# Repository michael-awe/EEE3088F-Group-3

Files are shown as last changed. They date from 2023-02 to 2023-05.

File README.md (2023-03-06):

# EEE3088F Project (Group 3)

This GitHub repository contains the source code and documentation for a sound and proximity light sensing HAT (Hardware Attached on Top) designed for an STM32F05C6T6 Discovery board. The repository contains detailed technical documentation with diagrams, schematics and specifications for the HAT's hardware and software.

## Project Description
Our HAT (Hardware Attached on Top) is a compact device that incorporates light proximity sensor and a sound sensor, making it an all-in-one solution for non-contact detection and monitoring. Designed to work seamlessly with STM 32 microcontrollers, the HAT offers both motion and sound sensing capabilities that make it an ideal choice for a wide range of use cases such as process monitoring, home automation, surveillance, and non-contact activation.  
With an onboard battery, the HAT can operate remotely for extended periods, providing reliable and accurate data capture during load-shedding. The HAT's data capture capabilities are enhanced by its micro-USB data transfer, which allows users to easily power the microcontroller and transfer data between it and a computer. Overall, the HAT is an excellent option for businesses and organizations looking for a cost-effective, reliable, and adaptable solution for non-contact detection and monitoring. 

## Team Members
1. Michael Awe (Microcontroller interfacing + Coding)
2. Adrian Mc Intosh (Sensor Module)
3. Simon Carthew (Power Module)

## License

This repository is licensed under the Creative Commons Attribution 4.0 International license. See `LICENSE.md` for more information.

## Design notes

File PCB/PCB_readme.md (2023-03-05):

# PCB

A folder to store all the KiCAD libraries aswell as the gerber and schematic files for the HAT.

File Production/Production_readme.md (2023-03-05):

# Production

A folder to store all the information a manufacturer may need to produce the HAT, as well as information concerning the budget surrounding the board.

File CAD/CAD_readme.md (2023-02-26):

# CAD_readme
Folder containg files related to mechanical design for the project such as 3D printing or container design files

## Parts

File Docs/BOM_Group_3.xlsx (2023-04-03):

JLCPCB PART NUM | MANUFACTURER PART NO. | EXTENDED PART | JLCPCB PART LINK | KICAD SCHEMATIC REFERENCE | COMPONENT VALUE | QTY PER BOARD | QTY FIVE BOARDS | PRICE PER UNIT ($) | PRICE PER BOARD ($) | PRIVE FIVE BOARDS ($) | PRICE FIVE BOARDS EXTENDED ($)
C15008 | CC0805KRX7R9BB104 | 0 | https://jlcpcb.com/partdetail/15681-CL31A107MQHNNNE/C15008 | C6 | 100u | 1 | 5 | 0.0046 | 0.0046 | 0.023 | 0.023 | SENSOR MODULE TOTALS
C28323 | CL21B105KBFNNNE | 0 | https://jlcpcb.com/partdetail/29074-CL21B105KBFNNNE/C28323 | C7 | 4.7u | 1 | 15 | 0.0095 | 0.0095 | 0.1425 | 0.1425 | One Board | $3.60
C149504 | 0805W8F1003T5E | 0 | https://jlcpcb.com/partdetail/160838-0805W8F1003T5E/C149504 | R23,R24 | 100k | 2 | 10 | 0.0017 | 0.0034 | 0.017 | 0.017 | Five Boards | $18.02
C4310 | 0805W8F1501T5E | 0 | https://jlcpcb.com/partdetail/4717-0805W8F1501T5E/C4310 | R 19 | 1.5k | 1 | 5 | 0.0018 | 0.0018 | 0.009 | 0.009
C17379 | 0805W8F1201T5E | 0 | https://jlcpcb.com/partdetail/18067-0805W8F1201T5E/C17379 | R 20 | 1.2k | 1 | 5 | 0.0018 | 0.0018 | 0.009 | 0.009 | MICROCONTROLLER MODULE TOTALS
C2655167 | VL6180V1NR/1 | 1 | https://test.jlcpcb.com/partdetail/Stmicroelectronics-VL6180V1NR1/C2655167 | VL6180 | PROX SENSOR | 1 | 5 | 2.0786 | 2.0786 | 10.393 | 13.393 | One Board | $3.54
C75510 | LM317AG-TN3-R | 0 | https://jlcpcb.com/partdetail/utc_unisonic_tech-LM317AG_TN3R/C75510 | Q8 | LM317AG | 1 | 5 | 0.1872 | 0.1872 | 0.936 | 0.936 | Five Boards | $17.72
C78284 | BSS138 | 1 | https://jlcpcb.com/partdetail/79418-BSS138/C78284 | Q4, Q6, Q7, Q8 | BSS138 | 4 | 15 | 0.0225 | 0.09 | 0.3375 | 3.3375
C17414 | 0805W8F1002T5E | 0 | 0805W8F1002T5E | UNI-ROYAL(Uniroyal Elec) | Chip Resistor - Surface Mount | JLCPCB (https://jlcpcb.com/partdetail/18102-0805W8F1002T5E/C17414) | R38, R39, R40, R41, R46, R47, R48, R49 | 10k | 8 | 15 | 0.00133333 | 0.01066664 | 0.01999995 | 0.01999995
C17477 | 0805W8F0000T5E | 0 | https://jlcpcb.com/partdetail/18165-0805W8F0000T5E/C17477 | R18,R21,R22,R25,R37,R43,R44,R50,R36,R42,R45,R51 | 0k | 12 | 60 | 0.0022 | 0.0264 | 0.132 | 0.132 | POWER MODULE TOTALS
 |  |  |  |  |  |  |  |  |  |  |  | One Board | $1.29
 |  |  |  |  |  |  |  |  |  |  |  | Five Boards | $9.46
JLCPCB PART NUM | MANUFACTURER PART NO. | EXTENDED PART | JLCPCB PART LINK | KICAD SCHEMATIC REFERENCE | COMPONENT VALUE | QTY PER BOARD | QTY FIVE BOARDS | PRICE PER UNIT ($) | PRICE PER BOARD ($) | PRIVE FIVE BOARDS ($) | PRICE FIVE BOARDS EXTENDED ($)
C7171 | TAJA106K016RNJ | 0 | https://jlcpcb.com/partdetail/KyoceraAvx-TAJA106K016RNJ/C7171 | C1, C4 | 10uF | 2 | 10 | 0.088 | 0.176 | 0.88 | 0.88
C49678 | CC0805KRX7R9BB104 | 0 | https://jlcpcb.com/partdetail/Yageo-CC0805KRX7R9BB104/C49678 | C8 | 0.1u | 1 | 5 | 0.0046 | 0.0046 | 0.023 | 0.023 | HAT TOTALS
C2286 | KT-0603R | 0 | https://jlcpcb.com/partdetail/Hubei_KentoElec-KT0603R/C2286 | LED1 | Red LED | 1 | 5 | 0.006 | 0.006 | 0.03 | 0.03 | Sensor Module | $18.02
C2297 | C2297 | 0 | https://jlcpcb.com/partdetail/Hubei_KentoElec-C2297/C2297 | LED2 | Green LED | 1 | 5 | 0.0133 | 0.0133 | 0.0665 | 0.0665 | Power Module | $9.46
C17414 | 0805W8F1002T5E | 0 | https://jlcpcb.com/partdetail/18102-0805W8F1002T5E/C17414 | R5, R6 | 10k | 2 | 10 | 0.00133333 | 0.00266666 | 0.0133333 | 0.0133333 | MicroController Interfacing | $17.72
C17477 | 0805W8F0000T5E | 0 | https://jlcpcb.com/partdetail/18165-0805W8F0000T5E/C17477 | R1, R2, R7, R8, R9, R17 | 0k | 6 | 30 | 0.0022 | 0.0132 | 0.066 | 0.066 | Manufacturing | $12.00
C17927 | C17927 | 0 | https://jlcpcb.com/partdetail/18615-1206W4F1004T5E/C17927 | R11, R13 | 1M | 2 | 10 | 0.0031 | 0.0062 | 0.031 | 0.031 | GRAND TOTAL | $57.20
C17927 | GZ2012D101TF | 0 | https://jlcpcb.com/partdetail/Sunlord-GZ2012D101TF/C1015 | R15, R16 | 100 | 2 | 10 | 0.0094 | 0.0188 | 0.094 | 0.094
C2857251 | ZMM2V0 | 1 | https://jlcpcb.com/partdetail/Jsmsemi-ZMM2V0/C2857251 | D2, D3 | D_Zener | 1 | 5 | 0.0103 | 0.0103 | 0.0515 | 3.0515
C4172 | 0603WAF1504T5E | 0 | https://jlcpcb.com/partdetail/4579-0603WAF1504T5E/C4172 | R10, R11 | 1.5M | 2 | 10 | 0.0017 | 0.0034 | 0.017 | 0.017
C22764 | 0603WAF1101T5E | 0 | https://jlcpcb.com/partdetail/23491-0603WAF1101T5E/C22764 | R3, R4, R14 | 1k | 3 | 15 | 0.002 | 0.006 | 0.03 | 0.03
C191023 | 1N5819WS | 0 | https://jlcpcb.com/partdetail/GuangdongHottech-1N5819WS/C191023 | D1, D2 | 1N5819 | 2 | 10 | 0.162 | 0.324 | 1.62 | 1.62
C7433 | OP07CDR | 0 | https://jlcpcb.com/partdetail/TexasInstruments-OP07CDR/C7433 | U3 | OP07 | 1 | 5 | 0.28 | 0.28 | 1.4 | 1.4
C8492 | LBSS84LT1G | 0 | https://jlcpcb.com/partdetail/Lrc-LBSS84LT1G/C8492 | Q2, Q3 | LBSS84LT1G | 2 | 10 | 0.0242 | 0.0484 | 0.242 | 0.242
C5446 | XC6206P332MR | 0 | https://jlcpcb.com/partdetail/TorexSemicon-XC6206P332MR/C5446 | U2 | XC6206P | 1 | 5 | 0.0964 | 0.0964 | 0.482 | 0.482
C15127 | AO3401A | 0 | https://jlcpcb.com/partdetail/Alpha_OmegaSemicon-AO3401A/C15127 | Q1 | AO3401A | 1 | 5 | 0.0797 | 0.0797 | 0.3985 | 0.3985
C16581 | TP4056-42-ESOP8 | 0 | https://jlcpcb.com/partdetail/17264-TP4056_42ESOP8/C16581 | U1 | TP4056 | 1 | 5 | 0.2027 | 0.2027 | 1.0135 | 1.0135
JLCPCB PART NUM | MANUFACTURER PART NO. | EXTENDED PART | JLCPCB PART LINK | KICAD SCHEMATIC REFERENCE | COMPONENT VALUE | QTY PER BOARD | QTY FIVE BOARDS | PRICE PER UNIT ($) | PRICE PER BOARD ($) | PRICE FIVE BOARDS ($) | PRICE FIVE BOARDS EXTENDED ($)
C404969 | MICROXNJ | 1 | https://jlcpcb.com/partdetail/ShouHan-MicroXNJ/C404969 | J6 | Micro-B USB Connector | 1 | 5 | 0.03 | 0.03 | 0.15 | 3.15
C79987 | CAT24C256WI-GT3 | 1 | https://jlcpcb.com/partdetail/Onsemi-CAT24C256WIGT3/C79987 | U6 | EEPROM | 1 | 5 | 0.43 | 0.43 | 2.15 | 5.15
C84681 | CH340C | 1 | https://jlcpcb.com/partdetail/wch_jiangsu_Qin_heng-CH340C/C84681 | U7 | USB to Serial | 1 | 5 | 0.47 | 0.47 | 2.35 | 5.35
C17477 | 0805W8F0000T5E | 0 | https://jlcpcb.com/partdetail/18165-0805W8F0000T5E/C17477 | R26, R27, R28, R31, R32, R33, R34, R35 | 0k | 8 | 40 | 0.0022 | 0.0176 | 0.088 | 0.088
C49678 | CC0805KRX7R9BB104 | 0 | https://jlcpcb.com/partdetail/Yageo-CC0805KRX7R9BB104/C49678 | C12 | 0.1uF | 1 | 5 | 0.0046 | 0.0046 | 0.023 | 0.023
C23162 | 0603WAF4701T5E | 0 | https://jlcpcb.com/parts/2nd/Resistors/Chip_Resistor_Surface_Mount_4 | R29, R30 | 4.7K | 2 | 10 | 0.001 | 0.002 | 0.01 | 0.01
C1525 | CL05B104KO5NNNC | 0 | https://jlcpcb.com/partdetail/1877-CL05B104KO5NNNC/C1525 | C13, C14 | 100nF | 2 | 10 | 0.01 | 0.02 | 0.1 | 0.1
C19666 | CL10A475KO8NNNC | 0 | https://jlcpcb.com/partdetail/20375-CL10A475KO8NNNC/C19666 | C15 | 4.7uF | 1 | 5 | 0.01 | 0.01 | 0.05 | 0.05
C15195 | CL05B103KB5NNNC | 0 | https://jlcpcb.com/partdetail/15869-CL05B103KB5NNNC/C15195 | C16 | 10nF | 1 | 5 | 0.01 | 0.01 | 0.05 | 0.05
C52923 | CL05A105KA5NQNC | 0 | https://jlcpcb.com/partdetail/53938-CL05A105KA5NQNC/C52923 | C17 | 1uF | 1 | 5 | 0.01 | 0.01 | 0.05 | 0.05
C107114 | CC0805JRNPO9BN300 | 0 | https://jlcpcb.com/partdetail/Yageo-CC0805JRNPO9BN300/C107114 | C10,C11 | 30pF | 2 | 10 | 0.01 | 0.02 | 0.1 | 0.1
C252310 | 6CS08000F20UCG | 1 | https://jlcpcb.com/partdetail/247485-6CS08000F20UCG/C252310 | Y1 | 8MHz, 20pF | 1 | 5 | 0.12 | 0.12 | 0.6 | 3.6

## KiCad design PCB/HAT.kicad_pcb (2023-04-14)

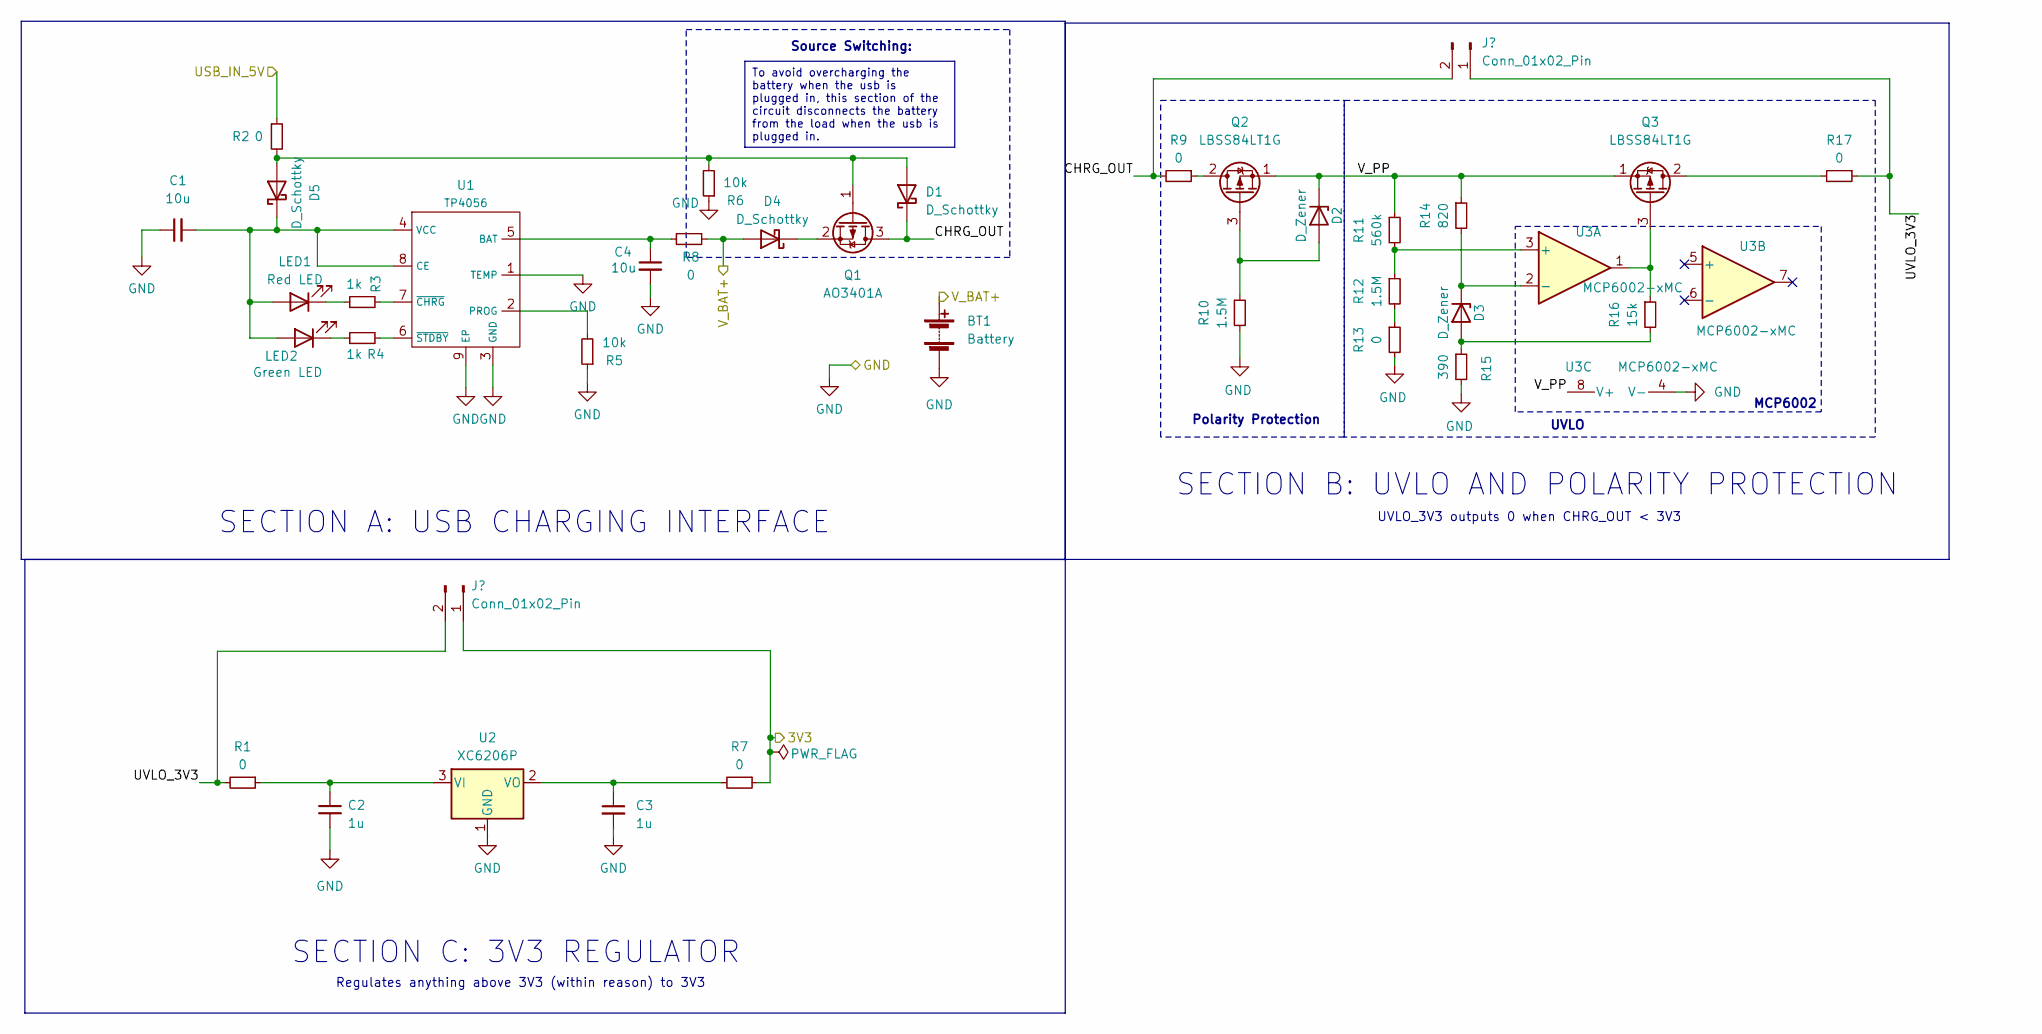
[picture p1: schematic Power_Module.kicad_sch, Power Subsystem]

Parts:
BT1: Battery; 18650_Holder_SMD
C1, C4: 10u; CAP-SMD_L3.2-W1.6-RD-C7171
C2, C3: 1u; C0402_NEW
D1, D4, D5: D_Schottky; SOD-323_L1.8-W1.3-LS2.5-RD
D2, D3: D_Zener; LL-34_L3.5-W1.5-RD
J1, J2: Conn_01x02_Pin; PinHeader_1x02_P2.54mm_Vertical
LED1: Red LED; LED0603-RD
LED2: Green LED; LED0805-R-RD
Q1: AO3401A; SOT-23
Q2, Q3: LBSS84LT1G; SOT-23_L2.9-W1.3-P1.90-LS2.4-BR
R1, R2, R7, R8, R9, R13, R17: 0; R_0805_2012Metric
R3, R4: 1k; R_0805_2012Metric
R5, R6: 10k; R_0805_2012Metric
R10: 1.5M; R_0805_2012Metric
R11: 560k; R_0603_1608Metric
R12: 1.5M; R_0603_1608Metric
R14: 820; R_0805_2012Metric
R15: 390; R_0805_2012Metric
R16: 15k; R_0805_2012Metric
U1: TP4056; SOIC-8-1EP_3.9x4.9mm_P1.27mm_EP2.29x3mm
U2: XC6206P; SOT-23-3
U3: MCP6002-xMC; DFN-8-1EP_3x2mm_P0.5mm_EP1.75x1.45mm

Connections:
/MicroController_Interfacing/3V3: J1.1, R7.1; also elsewhere on the board
/MicroController_Interfacing/USB 5V: R2.1; also elsewhere on the board
/Power Module/CHRG_OUT: D1.1 (K), J2.2, Q1.3 (D), R9.2
/Power Module/UVLO_3V3: J1.2, J2.1, R1.2, R17.1
/Power Module/V_BAT+: BT1.1 (+), D4.2 (A), R8.1; also elsewhere on the board
/Power Module/V_PP: D2.1 (K), Q2.1 (S), Q3.1 (S), R11.1, R14.1, U3.8 (V+)
GND: BT1.2 (-), C1.1, C2.2, C3.2, C4.2, R5.1, R6.1, R10.2, R13.2, R15.2, U1.1 (TEMP), U1.3 (GND), U1.9 (EP), U2.1 (GND), U3.4 (V-), U3.9 (V-); also elsewhere on the board
unnamed: D1.2 (A), D5.2 (A), Q1.1 (G), R2.2, R6.2
unnamed: D2.2 (A), Q2.3 (G), R10.1
unnamed: D3.2 (A), R15.1, R16.2
unnamed: D3.1 (K), R14.2, U3.2 (-)
unnamed: D4.1 (K), Q1.2 (S)
unnamed: C1.2, D5.1 (K), LED1.2 (A), LED2.2 (A), U1.4 (VCC), U1.8 (CE)
unnamed: LED1.1 (K), R3.1
unnamed: LED2.1 (K), R4.1
unnamed: Q2.2 (D), R9.1
unnamed: Q3.2 (D), R17.2
unnamed: Q3.3 (G), R16.1, U3.1
unnamed: R12.2, R13.1
unnamed: C4.1, R8.2, U1.5 (BAT)
unnamed: R5.2, U1.2 (PROG)
unnamed: R3.2, U1.7 (~CHRG)
unnamed: R4.2, U1.6 (~STDBY)
unnamed: C2.1, R1.1, U2.3 (VI)
unnamed: C3.1, R7.2, U2.2 (VO)
unnamed: R11.2, R12.1, U3.3 (+)

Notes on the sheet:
To avoid overcharging the battery when the usb is plugged in, this section of the circuit disconnects the battery from the load when the usb is plugged in.
Source Switching:
MCP6002
SECTION C: 3V3 REGULATOR
UVLO
SECTION B: UVLO AND POLARITY PROTECTION
SECTION A: USB CHARGING INTERFACE
UVLO_3V3 outputs 0 when CHRG_OUT < 3V3
Regulates anything above 3V3 (within reason) to 3V3
Polarity Protection

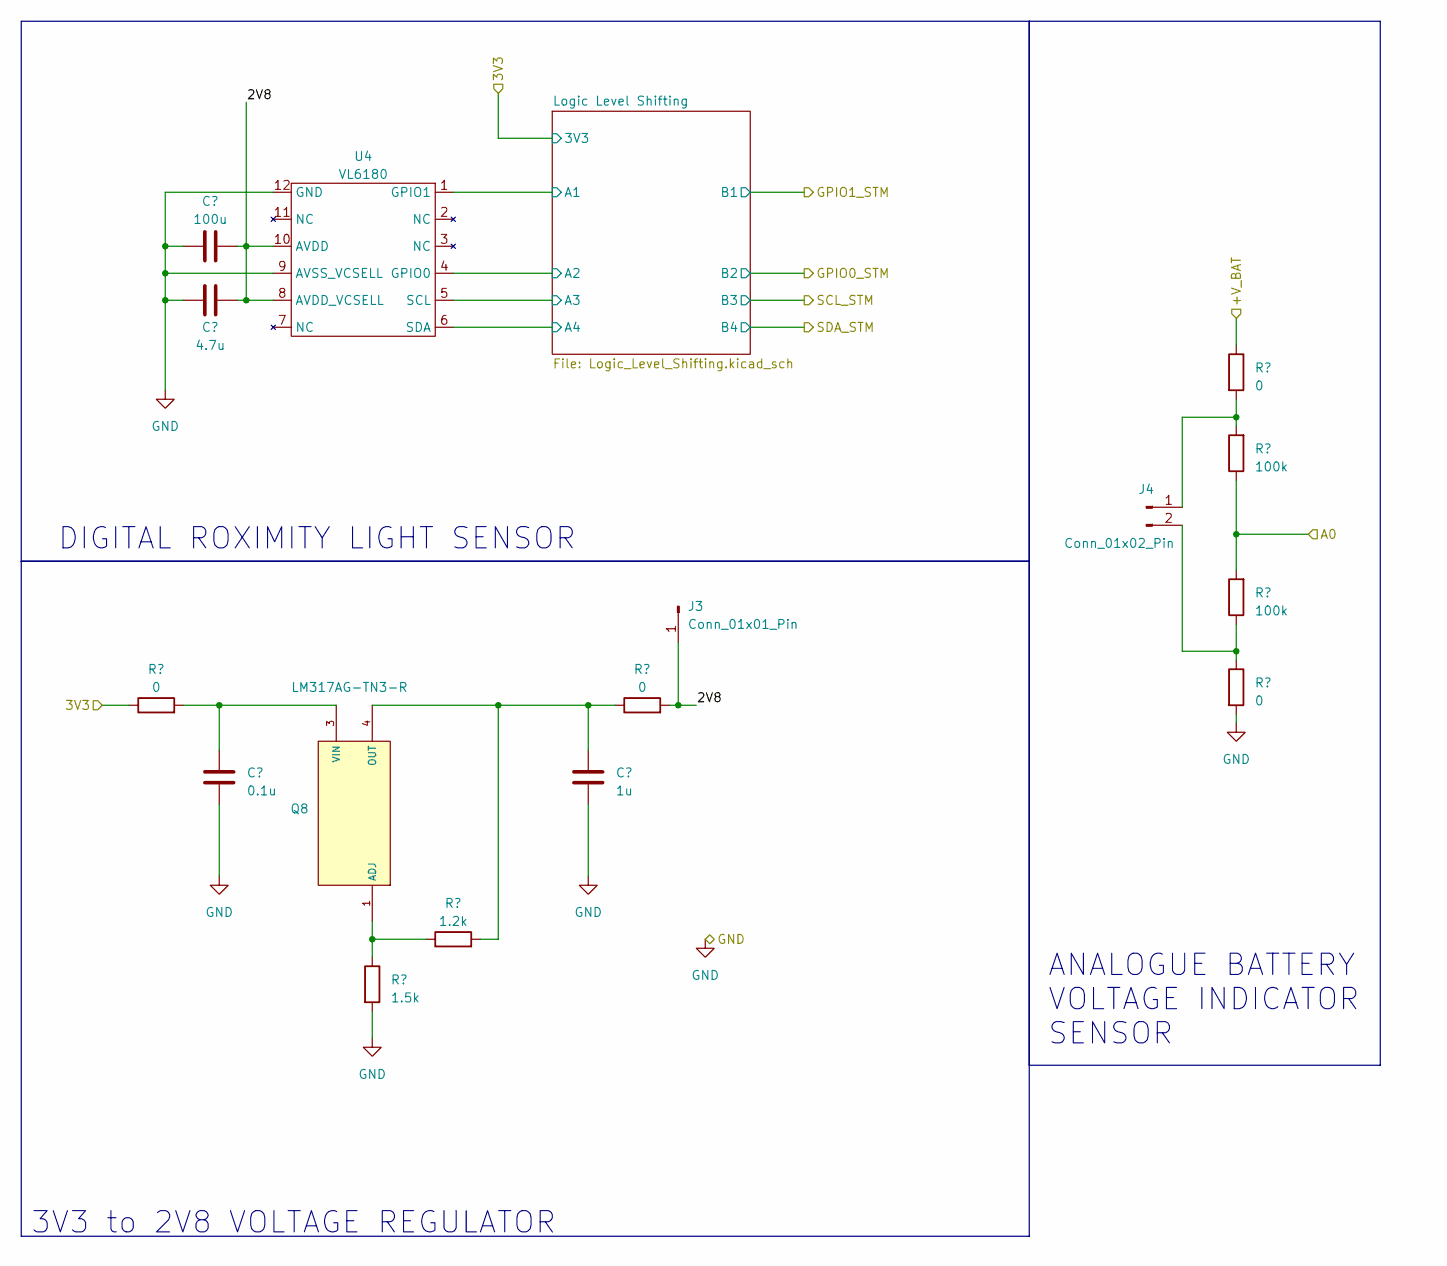
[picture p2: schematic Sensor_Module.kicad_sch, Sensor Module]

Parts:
C6: 100u; C1206
C7: 4.7u; C0603
C8: 0.1u; C0805
C9: 1u; C0402_NEW
J3: Conn_01x01_Pin; PinHeader_1x01_P2.54mm_Vertical
J4: Conn_01x02_Pin; PinHeader_1x02_P2.54mm_Vertical
Q8: LM317AG-TN3-R; TO-252-2_L6.5-W6.1-P4.58-LS10.0-TL; LCSC C75510
R18, R21, R22, R25: 0; R_0805_2012Metric
R19: 1.5k; R_0805_2012Metric
R20: 1.2k; R_0805_2012Metric
R23, R24: 100k; R_0805_2012Metric
U4: VL6180; LGA-12_L4.8-W2.8-P0.75-BL

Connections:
/MicroController_Interfacing/3V3: R18.1; also elsewhere on the board
/MicroController_Interfacing/A0: R23.1, R24.2; also elsewhere on the board
/Power Module/V_BAT+: R22.1; also elsewhere on the board
/Sensor Module/2V8: C6.1, C7.1, J3.1, R21.2, U4.8 (AVDD_VCSELL), U4.10 (AVDD)
/Sensor Module/Logic Level Shifting/A1: U4.1 (GPIO1); also elsewhere on the board
/Sensor Module/Logic Level Shifting/A2: U4.4 (GPIO0); also elsewhere on the board
/Sensor Module/Logic Level Shifting/A3: U4.5 (SCL); also elsewhere on the board
/Sensor Module/Logic Level Shifting/A4: U4.6 (SDA); also elsewhere on the board
GND: C6.2, C7.2, C8.1, C9.1, R19.2, R25.2, U4.9 (AVSS_VCSELL), U4.12 (GND); also elsewhere on the board
unnamed: J4.1, R22.2, R23.2
unnamed: J4.2, R24.1, R25.1
unnamed: Q8.1 (ADJ), R19.1, R20.1
unnamed: C9.2, Q8.4 (OUT), R20.2, R21.1
unnamed: C8.2, Q8.3 (VIN), R18.2

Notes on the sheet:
ANALOGUE BATTERY VOLTAGE INDICATOR SENSOR
DIGITAL ROXIMITY LIGHT SENSOR
3V3 to 2V8 VOLTAGE REGULATOR

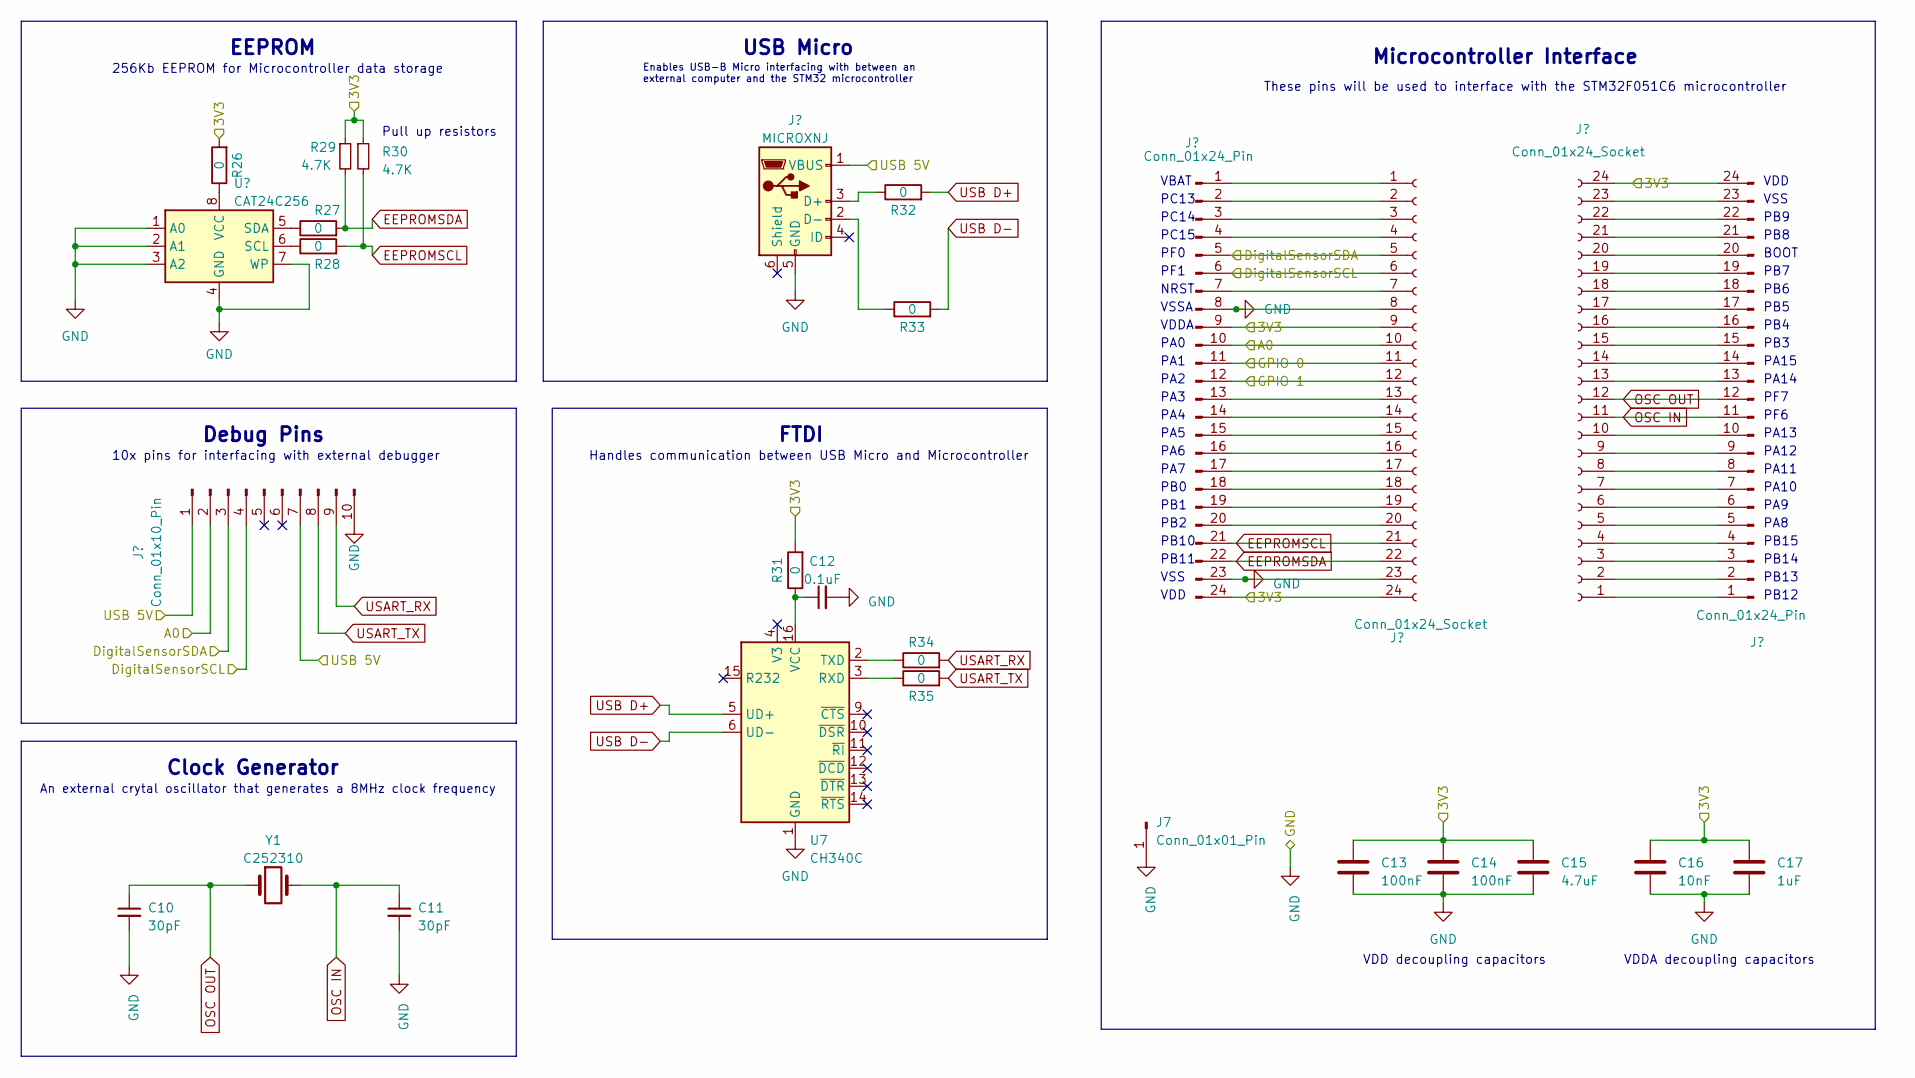
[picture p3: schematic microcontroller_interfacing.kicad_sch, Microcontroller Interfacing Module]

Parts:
C10, C11: 30pF; C0805
C12: 0.1uF; C0805
C13, C14: 100nF; C0402
C15: 4.7uF; C0603
C16: 10nF; C0402_NEW
C17: 1uF; C0402_NEW
J5: Conn_01x10_Pin; PinHeader_1x10_P2.54mm_Vertical
J6: MICROXNJ; USB_Conn_JLC_LCSC_C404969
J7: Conn_01x01_Pin; PinHeader_1x01_P2.54mm_Vertical
J8, J11: Conn_01x24_Pin; PinHeader_1x24_P2.54mm_Vertical
J9, J10: Conn_01x24_Socket; PinSocket_1x24_P2.54mm_Vertical
R26, R27, R28, R31, R32, R33, R34, R35: 0; R_0805_2012Metric
R29, R30: 4.7K; R_0805_2012Metric
U6: CAT24C256; SOIC-8_L4.9-W3.9-P1.27-LS6.0-BL
U7: CH340C; SOIC-16_3.9x9.9mm_P1.27mm
Y1: C252310; HC-49S_L11.4-W4.8

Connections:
/MicroController_Interfacing/3V3: C13.1, C14.1, C15.1, C16.1, C17.1, J8.9, J8.24, J9.9, J9.24, J10.24, J11.24, R26.2, R29.1, R30.1, R31.2; also elsewhere on the board
/MicroController_Interfacing/A0: J5.2, J8.10, J9.10; also elsewhere on the board
/MicroController_Interfacing/DigitalSensorSCL: J5.4, J8.6, J9.6; also elsewhere on the board
/MicroController_Interfacing/DigitalSensorSDA: J5.3, J8.5, J9.5; also elsewhere on the board
/MicroController_Interfacing/GPIO 0: J8.11, J9.11; also elsewhere on the board
/MicroController_Interfacing/GPIO 1: J8.12, J9.12; also elsewhere on the board
/MicroController_Interfacing/USB 5V: J5.1, J5.7, J6.1 (VBUS); also elsewhere on the board
EEPROMSCL: J8.21, J9.21, R28.2, R30.2
EEPROMSDA: J8.22, J9.22, R27.2, R29.2
GND: C10.2, C11.2, C12.2, C13.2, C14.2, C15.2, C16.2, C17.2, J5.10, J6.5 (GND), J7.1, J8.8, J8.23, J9.8, J9.23, U6.1 (A0), U6.2 (A1), U6.3 (A2), U6.4 (GND), U6.7 (WP), U7.1 (GND); also elsewhere on the board
unnamed: J6.3 (D+), R32.1
unnamed: J6.2 (D-), R33.1
unnamed: J8.1, J9.1
unnamed: J8.2, J9.2
unnamed: J8.3, J9.3
unnamed: J8.4, J9.4
unnamed: J8.7, J9.7
unnamed: J8.13, J9.13
unnamed: J8.14, J9.14
unnamed: J8.15, J9.15
unnamed: J8.16, J9.16
unnamed: J8.17, J9.17
unnamed: J8.18, J9.18
unnamed: J8.19, J9.19
unnamed: J8.20, J9.20
unnamed: J10.1, J11.1
unnamed: J10.2, J11.2
unnamed: J10.3, J11.3
unnamed: J10.4, J11.4
unnamed: J10.5, J11.5
unnamed: J10.6, J11.6
unnamed: J10.7, J11.7
unnamed: J10.8, J11.8
unnamed: J10.9, J11.9
unnamed: J10.10, J11.10
unnamed: J10.13, J11.13
unnamed: J10.14, J11.14
unnamed: J10.15, J11.15
unnamed: J10.16, J11.16
unnamed: J10.17, J11.17
unnamed: J10.18, J11.18
unnamed: J10.19, J11.19
unnamed: J10.20, J11.20
unnamed: J10.21, J11.21
unnamed: J10.22, J11.22
unnamed: J10.23, J11.23
unnamed: R28.1, U6.6 (SCL)
unnamed: R27.1, U6.5 (SDA)
unnamed: R26.1, U6.8 (VCC)
unnamed: R35.1, U7.3 (RXD)
unnamed: R34.1, U7.2 (TXD)
unnamed: C12.1, R31.1, U7.16 (VCC)
OSC IN: C11.1, J10.11, J11.11, Y1.2
OSC OUT: C10.1, J10.12, J11.12, Y1.1
USART_RX: J5.9, R34.2
USART_TX: J5.8, R35.2
USB D+: R32.2, U7.5 (UD+)
USB D-: R33.2, U7.6 (UD-)

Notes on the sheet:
BOOT
PA4
PB6
PA14
PB3
PA2
Microcontroller Interface
PB10
VSSA
VSS
VDD
VBAT
PC13
PF1
PA11
Clock Generator
256Kb EEPROM for Microcontroller data storage
NRST
10x pins for interfacing with external debugger
PA12
PF0
VDDA
USB Micro
PB0
PA8
PA13
PA15
PA7
PA9
Pull up resistors
PA5
PC15
These pins will be used to interface with the STM32F051C6 microcontroller
PB4
PA3
PB11
Handles communication between USB Micro and Microcontroller
PB12
PC14
An external crytal oscillator that generates a 8MHz clock frequency

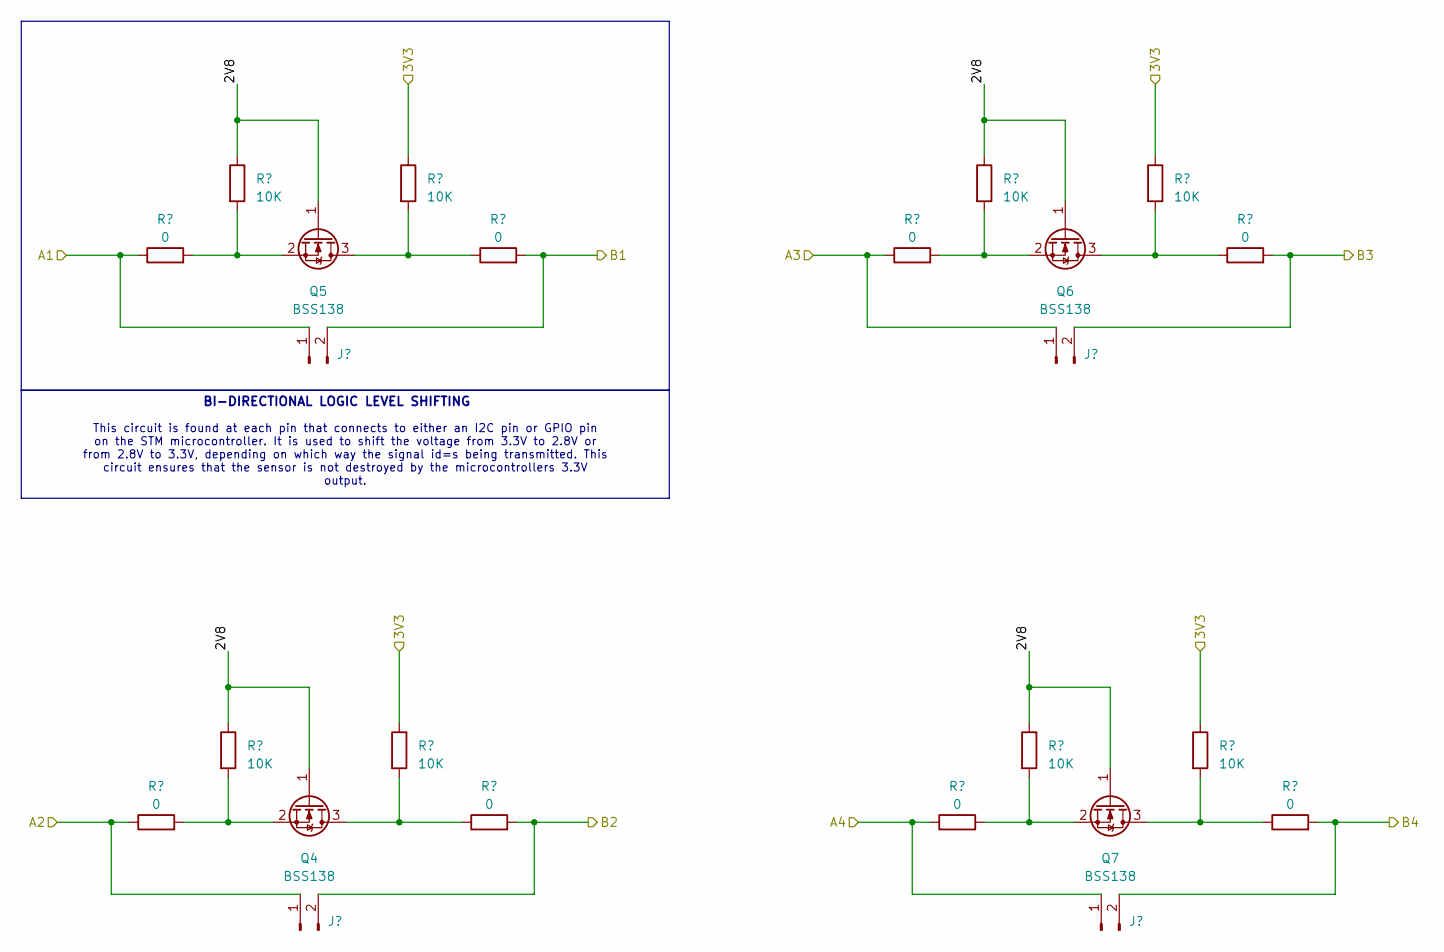
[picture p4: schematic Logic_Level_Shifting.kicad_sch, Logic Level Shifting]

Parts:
J12, J13, J14, J15: Conn_01x02_Pin; PinHeader_1x02_P2.54mm_Vertical
Q4, Q5, Q6, Q7: BSS138; SOT-23-3_L2.9-W1.3-P1.90-LS2.4-BR
R36, R37, R42, R43, R44, R45, R50, R51: 0; R_0805_2012Metric
R38, R39, R40, R41, R46, R47, R48, R49: 10K; R_0805_2012Metric

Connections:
/MicroController_Interfacing/3V3: R40.1, R41.1, R48.1, R49.1; also elsewhere on the board
/MicroController_Interfacing/DigitalSensorSCL: J14.2, R50.2; also elsewhere on the board
/MicroController_Interfacing/DigitalSensorSDA: J15.2, R51.2; also elsewhere on the board
/MicroController_Interfacing/GPIO 0: J12.2, R42.2; also elsewhere on the board
/MicroController_Interfacing/GPIO 1: J13.2, R43.2; also elsewhere on the board
/Sensor Module/Logic Level Shifting/2V8: Q4.1 (G), Q5.1 (G), Q6.1 (G), Q7.1 (G), R38.1, R39.1, R46.1, R47.1
/Sensor Module/Logic Level Shifting/A1: J13.1, R37.1; also elsewhere on the board
/Sensor Module/Logic Level Shifting/A2: J12.1, R36.1; also elsewhere on the board
/Sensor Module/Logic Level Shifting/A3: J14.1, R44.1; also elsewhere on the board
/Sensor Module/Logic Level Shifting/A4: J15.1, R45.1; also elsewhere on the board
unnamed: Q4.3 (D), R40.2, R42.1
unnamed: Q4.2 (S), R36.2, R38.2
unnamed: Q5.3 (D), R41.2, R43.1
unnamed: Q5.2 (S), R37.2, R39.2
unnamed: Q6.3 (D), R48.2, R50.1
unnamed: Q6.2 (S), R44.2, R46.2
unnamed: Q7.3 (D), R49.2, R51.1
unnamed: Q7.2 (S), R45.2, R47.2

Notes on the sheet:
This circuit is found at each pin that connects to either an I2C pin or GPIO pin on the STM microcontroller. It is used to shift the voltage from 3.3V to 2.8V or from 2.8V to 3.3V, depending on which way the signal id=s being transmitted. This circuit ensures that the sensor is not destroyed by the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
BI-DIRECTIONAL LOGIC LEVEL SHIFTING

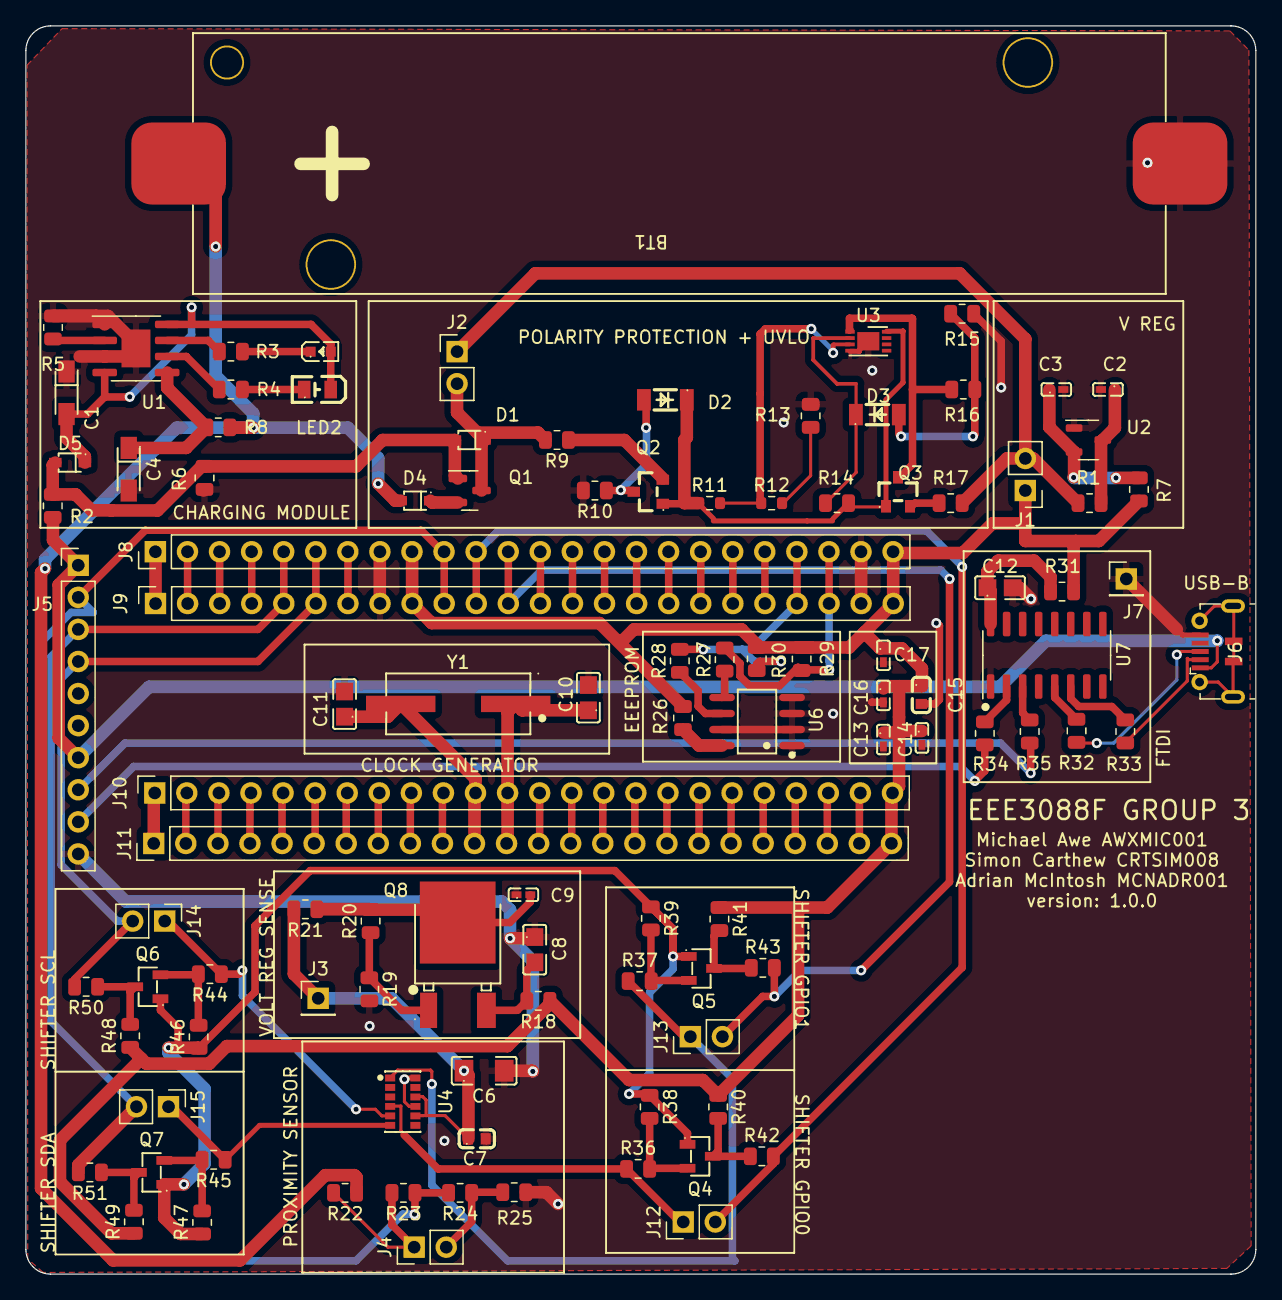
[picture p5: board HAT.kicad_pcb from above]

Board: 2 copper layers, 97.4 x 98.8 mm, 105 parts (0 on the bottom side), 100 nets.

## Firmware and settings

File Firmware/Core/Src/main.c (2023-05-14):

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
/* Includes ------------------------------------------------------------------*/
#include "main.h"

ADC_HandleTypeDef hadc;

I2C_HandleTypeDef hi2c1;

UART_HandleTypeDef huart1;

/* USER CODE BEGIN PV */
I2C_HandleTypeDef hi2c2;
static const uint8_t TMP102_ADDR = 0x4D << 1; // Use 8-bit address
static const uint8_t REG_TEMP = 0x00;
/* USER CODE END PV */

void SystemClock_Config(void);
static void MX_GPIO_Init(void);
static void MX_I2C1_Init(void);
static void MX_USART1_UART_Init(void);
static void MX_ADC_Init(void);
/* USER CODE BEGIN PFP */
static void MX_I2C2_Init(void);
/* USER CODE END PFP */

/**
  * @brief  The application entry point.
  * @retval int
  */
int main(void)
{
  /* USER CODE BEGIN 1 */
  HAL_StatusTypeDef ret;
  uint8_t buf[12];
  int16_t val;
  float temp_c;
  /* USER CODE END 1 */

  /* MCU Configuration--------------------------------------------------------*/

  /* Reset of all peripherals, Initializes the Flash interface and the Systick. */
  HAL_Init();

  /* Configure the system clock */
  SystemClock_Config();

  /* Initialize all configured peripherals */
  MX_GPIO_Init();
  MX_I2C1_Init();
  MX_USART1_UART_Init();
  MX_ADC_Init();
  /* USER CODE BEGIN 2 */
  MX_I2C2_Init();
  HAL_GPIO_WritePin(GPIOB, GPIO_PIN_3, GPIO_PIN_SET);
  HAL_Delay(100);
  /* USER CODE END 2 */

  /* Infinite loop */
  /* USER CODE BEGIN WHILE */
  while (1)
  {
    /* USER CODE END WHILE */

    /* USER CODE BEGIN 3 */
  }
  /* USER CODE END 3 */
}

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
/* USER CODE BEGIN 4 */
/**
  * @brief I2C1 Initialization Function
  * @param None
  * @retval None
  */
static void MX_I2C2_Init(void)
{

  hi2c2.Instance = I2C2;
  hi2c2.Init.Timing = 0x2000090E;
  hi2c2.Init.OwnAddress1 = 0;
  hi2c2.Init.AddressingMode = I2C_ADDRESSINGMODE_7BIT;
  hi2c2.Init.DualAddressMode = I2C_DUALADDRESS_DISABLE;
  hi2c2.Init.OwnAddress2 = 0;
  hi2c2.Init.OwnAddress2Masks = I2C_OA2_NOMASK;
  hi2c2.Init.GeneralCallMode = I2C_GENERALCALL_DISABLE;
  hi2c2.Init.NoStretchMode = I2C_NOSTRETCH_DISABLE;
  if (HAL_I2C_Init(&hi2c2) != HAL_OK)
  {
    Error_Handler();
  }

  /** Configure Analogue filter
  */
  if (HAL_I2CEx_ConfigAnalogFilter(&hi2c2, I2C_ANALOGFILTER_ENABLE) != HAL_OK)
  {
    Error_Handler();
  }

  /** Configure Digital filter
  */
  if (HAL_I2CEx_ConfigDigitalFilter(&hi2c2, 0) != HAL_OK)
  {
    Error_Handler();
  }
}
/* USER CODE END 4 */
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


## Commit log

2023-02-26 CAD 2
2023-02-26 CAD 3
2023-03-06 Added microcontroller interfacing BOM
    [Microcontroller_Interfacing_BOM.xlsx]
2023-03-06 added power circuit schematic
    [power.kicad_sch]
2023-03-09 some updated changes to power circuit
    [power.kicad_sch]
2023-03-09 Made KiCAD project
    [HAT.kicad_pcb, HAT.kicad_sch, Power_Module.kicad_sch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]
2023-03-12 Add microcontroller interfacing schematic
    [HAT.kicad_sch, Power_Module.kicad_sch, Sensor_Module.kicad_sch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]
2023-03-12 Revert "Add microcontroller interfacing schematic"
    This reverts commit cb65be9f095c25773123ea45fc6a49ffd102fb8b.
    [HAT.kicad_sch, Power_Module.kicad_sch, Sensor_Module.kicad_sch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]
2023-03-12 MERGING SCHEMATICS
    [HAT.kicad_sch, Power_Module.kicad_sch, Sensor_Module.kicad_sch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]
2023-03-12 Changed Sensor Sheet Description
    [HAT.kicad_sch, Power_Module.kicad_sch, Sensor_Module.kicad_sch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]
2023-03-13 updated everything for Week 4 submission
    [HAT.kicad_sch, Power_Module.kicad_sch, Sensor_Module.kicad_sch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]
2023-03-13 Merging Fixed
    [Sensor_Module.kicad_sch]
2023-03-13 Update MC Interfacing schematic
    [HAT.kicad_sch, Power_Module.kicad_sch, Sensor_Module.kicad_sch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]
2023-03-13 UPDATED AND MERGED BOM
    [BOM_Group_3.xlsx, Microcontroller_Interfacing_BOM.xlsx, Power_Module_BOM.xlsx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]
2023-03-13 Add GND jumper pin to STM-32
    [microcontroller_interfacing.kicad_sch]
2023-03-13 Updated BOM
    [BOM_Group_3.xlsx]
2023-03-16 Changed Sensor and added hierachiel sheet
    [HAT.kicad_sch, Logic_Level_Shifting.kicad_sch, Power_Module.kicad_sch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]
2023-03-20 Add GPIO pins and crystal oscillator
    [microcontroller_interfacing.kicad_sch]
2023-03-20 updated schematic
    [HAT.kicad_sch, Power_Module.kicad_sch, Sensor_Module.kicad_sch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]
2023-03-20 Merging commit
    [HAT.kicad_sch, Logic_Level_Shifting.kicad_sch, Power_Module.kicad_sch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]
2023-03-20 commenting of trace thicknesses
    [HAT.kicad_sch, Logic_Level_Shifting.kicad_sch, Power_Module.kicad_sch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]
2023-03-20 Update MC schematic
    [HAT.kicad_sch, Logic_Level_Shifting.kicad_sch, Power_Module.kicad_sch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]
2023-03-20 changes to schematic based on available components
    [Power_Module.kicad_sch]
2023-03-20 literally all the footprints
    [HAT-CuBottom.gbr, HAT-CuTop.gbr, HAT-EdgeCuts.gbr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]
2023-03-20 sensor layout pcb
    [HAT.kicad_pcb, Logic_Level_Shifting.kicad_sch]
2023-03-20 Modified PCB
    [HAT.kicad_pcb]
2023-03-21 DRCs done
    [HAT-B_Cu.gbr, HAT-B_Mask.gbr, HAT-B_Paste.gbr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]
2023-03-21 updated Gerbers!
    [HAT-B_Cu.gbr, HAT-B_Mask.gbr, HAT-B_Paste.gbr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]
2023-03-21 Updated BOM!
    [BOM_Group_3.xlsx]
2023-04-03 Fixed via issues on PCB
    [BOM_Group_3.xlsx, HAT.kicad_pcb, Power_Module.kicad_sch]
2023-04-03 fixing of PCB Design
    [HAT.kicad_pcb, microcontroller_interfacing.kicad_sch]
2023-04-03 Pins not Sockets
    [HAT-CuBottom.gbr, HAT-CuTop.gbr, HAT-EdgeCuts.gbr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]
2023-04-03 Add LCSC numbers
    [HAT-CuBottom.gbr, HAT-CuTop.gbr, HAT-EdgeCuts.gbr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]
2023-04-04 updated power cct and PCB
    [HAT.kicad_pcb, Power_Module.kicad_sch]
2023-04-04 Update BOM, position files and gerbers
    [HAT-CuBottom.gbr, HAT-CuTop.gbr, HAT-EdgeCuts.gbr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]
2023-04-14 simon changes
    [HAT.kicad_pcb, Power_Module.kicad_sch]
2023-04-14 final pcb and chematic changes
    [HAT.kicad_pcb, Power_Module.kicad_sch]
2023-04-14 actual final pcb and schematic changes
    [HAT.kicad_pcb, Power_Module.kicad_sch]
2023-05-14 First Firmware
    [EEE3088F_Prox_Board Debug.cfg]

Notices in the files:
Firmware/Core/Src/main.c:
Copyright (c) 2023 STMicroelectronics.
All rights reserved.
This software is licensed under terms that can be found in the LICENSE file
